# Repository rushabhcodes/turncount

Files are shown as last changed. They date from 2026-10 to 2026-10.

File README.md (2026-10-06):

# TurnCount

TurnCount is a 48 mm round, two-layer rotary encoder prototype. The current circuit uses a CR2032 coin cell, a bare Nordic nRF52810-QFAA-R QFN-48, and a low-profile SMD encoder. USB-C charging and the LiPo charger/regulator path have been removed. The coin cell feeds the nRF52810 supply directly; its 1.7–3.6 V operating range accommodates a CR2032 over its discharge curve.

This remains a design review prototype, not a fabrication release. The CR2032 holder, RF layout and antenna tuning need physical review. The nRF52810 requires its supply decoupling, DEC capacitors, ground exposed pad, RF matching network and antenna, which are represented in the circuit.

## Main parts

| Function | Part |
| --- | --- |
| BLE MCU | Nordic nRF52810-QFAA-R, QFN-48; JLCPCB C141828 |
| Battery holder | MY-2032-16 CR2032 holder; JLCPCB C2902340 |
| RF antenna | RFANT3216120A5T; JLCPCB C127629 |
| Encoder | GT-EVA01AA-L1 |

GPIO assignments are P0.11 for A, P0.12 for B, P0.13 for push and P0.14 for the debug LED. SWDIO, SWDCLK and reset are exposed on test pads. The CR2032 holder mounts on the underside; check clearance against any future enclosure before fabrication.

## JLCPCB fabrication settings

The board explicitly uses 0.30 mm drilled through-vias with 0.60 mm copper pads
(0.15 mm radial annular ring), tented on both sides. JLCPCB lists extra charges
for 0.10/0.15 mm via holes and for 0.20/0.25 mm holes with pads below 0.45 mm;
these standard 0.30/0.60 mm vias avoid that small-hole category. Routing uses
0.15 mm minimum trace width and trace-to-pad clearance, 0.15 mm pad clearance,
0.20 mm hole and via-to-pad clearance, 0.45 mm via drill-to-drill clearance,
and 0.30 mm copper
clearance from the routed outline. The encoder's two 0.60 mm non-plated locating
holes exceed the 0.50 mm NPTH minimum.

For the economical PCB quote, use two-layer FR-4, 1.6 mm thickness, 1 oz copper,
green solder mask, standard outline tolerance and tented vias. Do not request
filled/capped vias, blind/buried vias, edge plating or controlled impedance.
Surface finish and assembly services affect the quote separately; confirm the
final Gerbers in JLCPCB's DFM/quote before ordering. Re-export fabrication files
after changing these rules; an older Gerber ZIP does not inherit source changes.

Requirements: <https://jlcpcb.com/capabilities/pcb-capabilities>.

Validation is reproducible with `npm run check`: all eight CLI check types,
TypeScript, the routed build, and the manufacturing dimension audit must pass.
The pin specification check retains two nonblocking warnings for passive imported
encoder/crystal parts without power-pin metadata. Bare test pads have no courtyard.

Verified routes are stored in `routing/pcb-trace-paths.json` and loaded by an
explicit routing phase. Changes to pad locations or footprints require updating
these routes and repeating the checks before exporting. The latest fabrication
bundle and validation summary are saved in `manufacturing/`.

The CLI doctor reports an npm authentication-header logging diagnostic despite
matching registry credentials. This is separate from the circuit checks; registry
publication verifies the active session directly.

## Umbrella enclosure

The default assembly now includes a 60 mm full-depth rotating cover, a snap-in lid,
a base with integrated PCB supports, and a pocket for an accessory-side MagSafe
magnet ring. See [the print and assembly guide](enclosure/ASSEMBLY.md). The complete
PCB remains in `TurnCountBoard.tsx`; `assembly.cadassembly` groups the enclosure
parts alongside it in the default `assembly.device`, following the
[tscircuit assembly documentation](https://docs.tscircuit.com/elements/assembly-cadassembly).

Open `enclosure/output/preview.html` for assembled, exploded, and underside views.
The output directory also includes three printable STL parts, tip-fit coupons,
and assembled/exploded GLB models. Measure the purchased magnet module and fit-test
the small encoder drive before printing the complete enclosure.

## Local decoupling

Each nRF52810 VDD pin now has its own 100 nF capacitor: C1/VDD1,
C2/VDD2, and C15/VDD3. C8–C11 decouple DEC1–DEC4 with the Nordic
reference values. The local supply paths have a 3 mm limit and
`npm run check` verifies their actual continuous top-layer copper paths,
capacitor values, and ground connections. It fails if any local path is
missing or too long. Reference values follow the [Nordic nRF52810
reference circuitry](https://docs.nordicsemi.com/r/bundle/ps_nrf52810/page/ref_circuitry.html). Shared ground routing is checked separately for
connectivity and copper shorts.

The project pins the latest registry releases checked on 6 October 2026:
`tscircuit` 0.0.2745 and `@tscircuit/cli` 0.1.2252. `circuit-json` stays at
0.0.515, the version required by the CLI's peer dependency.

## Build

```sh
npm install
npm run check
```

The PCB uses exact imported JLCPCB footprints for the nRF52810, battery holder, RF antenna, encoder and LED. Check current stock, verify the selected footprints and RF network against the Nordic reference design, and tune the antenna on the assembled board before treating this as a production design.

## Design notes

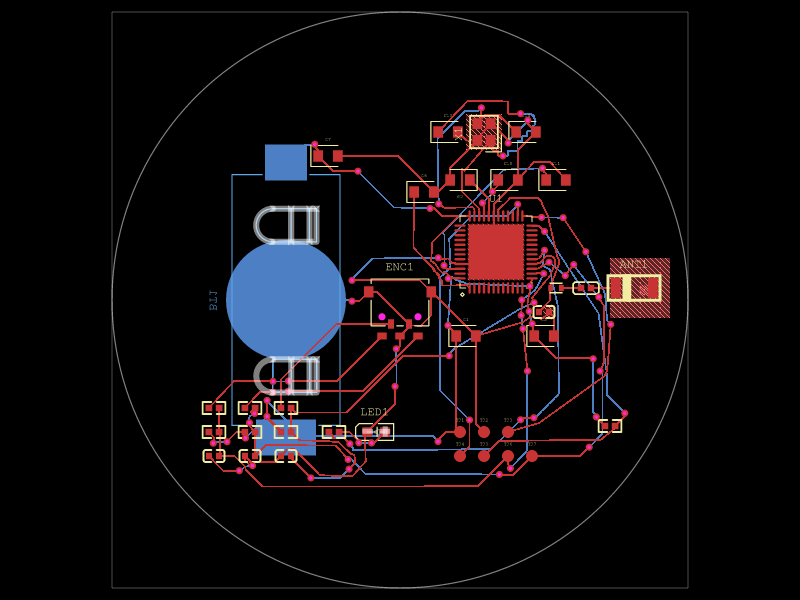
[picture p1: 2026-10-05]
docs/pcb-coin-cell.png

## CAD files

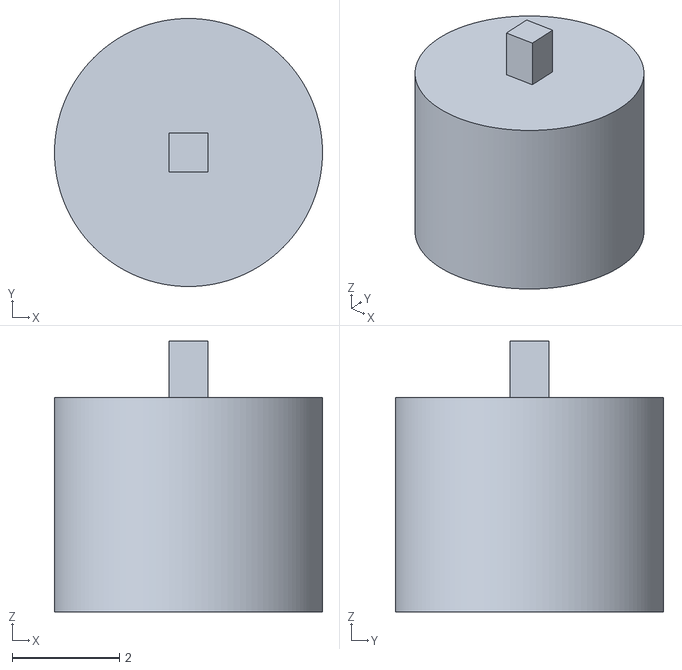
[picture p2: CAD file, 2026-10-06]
enclosure/output/tip-fit-0.72mm.stl
5.00 x 5.00 x 5.05

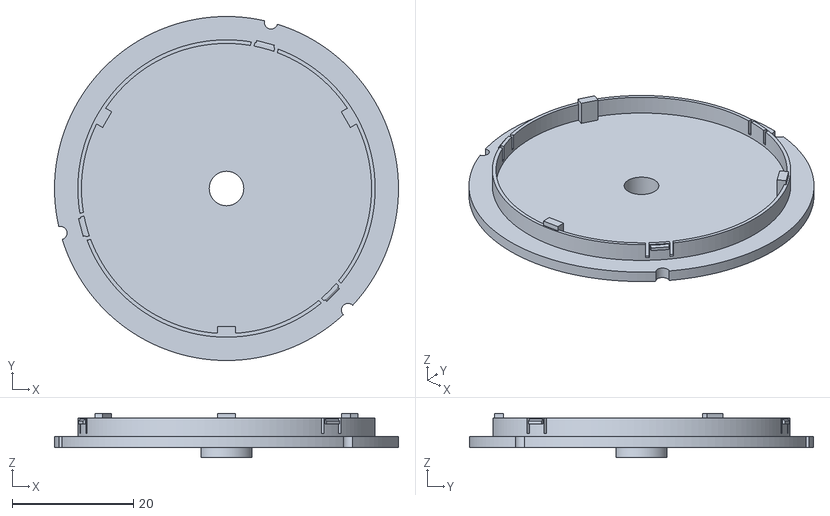
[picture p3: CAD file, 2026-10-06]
enclosure/output/lid.stl
56.8 x 56.8 x 7.30

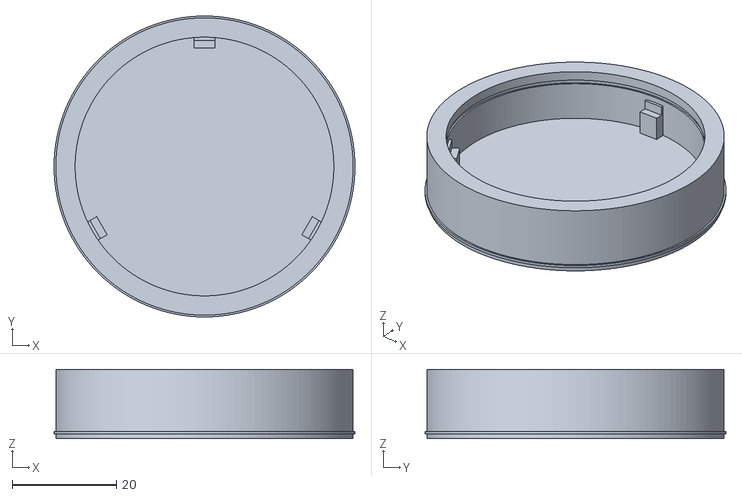
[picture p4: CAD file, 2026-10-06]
enclosure/output/base.stl
57.7 x 57.7 x 13.3

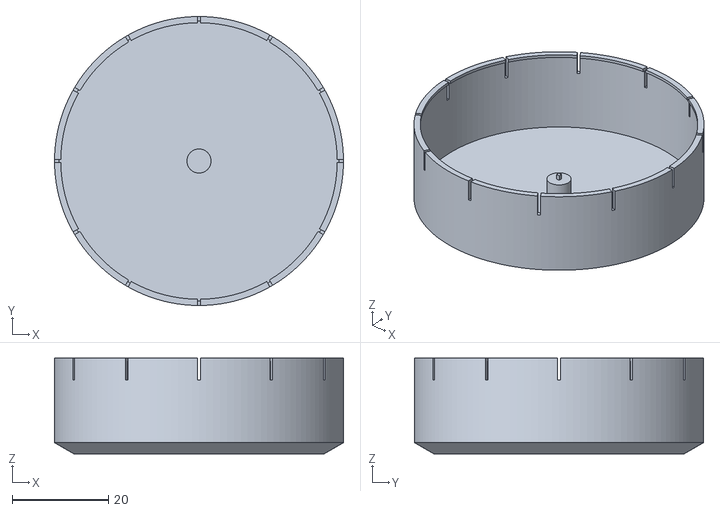
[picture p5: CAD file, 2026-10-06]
enclosure/output/knob.stl
60.0 x 60.0 x 19.9

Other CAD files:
enclosure/output/tip-fit-0.84mm.stl
enclosure/output/tip-fit-0.80mm.stl
enclosure/output/tip-fit-0.76mm.stl

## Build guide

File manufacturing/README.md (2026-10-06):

# TurnCount fabrication bundle — 1.0.19

`turncount-gerbers.zip` contains the latest routed two-layer board export.
Use 1.6 mm FR-4, 1 oz copper, green solder mask, standard outline tolerance,
and tented through-vias for the standard PCB quote.

All 47 plated holes are 0.30 mm with 0.60 mm copper pads. Both mask layers
cover the vias. The two encoder locating holes are 0.60 mm non-plated holes.
`validation-summary.json` records the passing circuit and dimension checks.
Reproduce validation with `npm run check`.

The export also contains BOM and placement data. Battery-holder rotation has
not been automatically verified because the imported footprint lacks a pin-1
location. Check that rotation before ordering assembly. Passive encoder/crystal
power-pin metadata and bare test-pad courtyard warnings remain nonblocking.
The design still requires physical holder review and RF/antenna tuning.

The CLI doctor authentication-header logging diagnostic remains; it does not
change the passing circuit checks. Confirm the final manufacturing quote with
JLCPCB, since finish, assembly, and order options affect pricing separately.

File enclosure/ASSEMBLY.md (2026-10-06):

# TurnCount full-depth dial enclosure

Three printed parts: **base**, **lid**, and **knob**. The 60 mm rotating knob covers the entire PCB and extends down around the 57 mm fixed base, almost to its bottom. Overall height including the phone contact film is 20.7 mm. PCB supports, the encoder drive, and retention snaps are integrated; there are no assembly screws or separate shaft inserts.

## Files and printing

- `output/base.stl`: base with PCB ledges, magnet pocket, and knob retention bead.
- `output/lid.stl`: snap-in lid with PCB clamp fingers and central shaft guide.
- `output/knob.stl`: full-depth rotating cover with integrated square encoder tip.
- `output/tip-fit-*.stl`: optional small test coupons, not assembly parts.
- `output/preview.html`: offline interactive assembly, exploded, and underside views.
- `output/turncount-assembled.glb` and `turncount-exploded.glb`: native tscircuit assembly models.

STLs use millimetres and are positioned on the print bed. Print the base upright. The lid is exported guide side down; support its flat face around the guide. The knob is exported top down, with its skirt and integrated shaft pointing upward. Use a tough material suitable for flexible snaps. A calibrated tough-resin printer is preferable for the small encoder tip; fine-nozzle PETG is a possible prototype route. Test the coupons before committing to the full knob.

The GT-EVA01AA-L1 drawing specifies a 0.8 ± 0.03 mm square drive opening. The nominal printed tip is 0.76 mm. Print coupons from 0.72 to 0.84 mm, choose a gentle sliding fit, and update `squareDrive` in `enclosure/dimensions.ts` if necessary. The actual encoder engagement depth must also be confirmed physically. Never force a tip into the encoder.

## Purchased items

Use an **accessory-side MagSafe magnet module**, correctly polarized, preferably supplied with its shielding. A plain steel adhesive ring is not the specified magnetic module. The nominal magnetic ring is 54.1 mm outside diameter and 46 mm inside diameter. This pocket is 54.5 mm outside diameter, 45.6 mm inside diameter, and 2.15 mm deep; the complete module including adhesive and shield must fit within the 2 mm modeled envelope. Measure the purchased module before printing.

Add a 0.8 mm soft phone-facing film, approximately 56.8 mm diameter, and three 0.2 mm compliant PCB clamp pads. The ring and film use thin adhesive; the printed assembly itself snaps together. The underside reference geometry represents the module envelope, not its individual magnet segments.

## Assembly

1. Secure the correctly oriented magnet module in the underside pocket. Apply the soft contact film so no hard print edge contacts the phone.
2. Install the battery, then seat the PCB on the three built-in base ledges. The supports keep the bottom battery holder clear of the floor.
3. Apply the three thin clamp pads beneath the lid fingers. Align the lid clips with the base groove and press the lid into place evenly.
4. Gently align the knob's integrated square tip with the encoder opening through the lid guide. Lower the knob and flex its lower skirt over the base retention bead. Do not use the snap force to force the shaft into the encoder.
5. Confirm a full turn, free return after pressing, and secure retention. The cover has 0.2 mm of modeled press travel. Its rim remains approximately 0.65 mm above the phone contact surface at full press.

For servicing, remove the device from the phone, ease the flexible lower skirt outward and lift the knob evenly. The lid has three edge notches for gentle release.

## Geometry and validation

The knob's 12 short skirt slots provide flex for assembly. The lower lip catches the base bead when lifted; the operating position leaves room to rotate and press. The lid bore guides the shaft while the base supports carry PCB loads.

`npm run enclosure:export` exports watertight meshes with the Manifold kernel and checks material intersections at eleven knob angles, both released and pressed. It also checks the PCB, battery-holder envelope, magnet pocket, and conservative top-side component envelopes. These checks cover operating clearances, not material flex, wear, magnetic holding force, or real print tolerances. Fit-test the shaft and snaps and check antenna performance with the magnet and enclosure installed before production.

The assembly uses documented `assembly.device` and `assembly.printedpart` elements, with the unchanged PCB in `TurnCountBoard.tsx`.

References: [tscircuit assembly](https://docs.tscircuit.com/elements/assembly-device), [printed parts](https://docs.tscircuit.com/elements/assembly-printedpart), [encoder drawing](https://datasheet.lcsc.com/datasheet/pdf/d558dce12d76d23321eaeb216a98bcc8.pdf), and [Apple accessory guidelines](https://developer.apple.com/accessories/Accessory-Design-Guidelines.pdf).

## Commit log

2026-10-02 Add TurnCount circuit draft and snapshots
2026-10-02 Use no-download tscircuit imports for encoder and holder
    [MDBT42Q.step]
2026-10-02 Use JLCPCB SMD encoder on a circular 48 mm prototype
2026-10-02 Add USB-C rechargeable supply and low-profile JLCPCB encoder
2026-10-03 Add rechargeable TurnCount enclosure and updated PCB
    [01_lower_tray.stl, 01_lower_tray_assembly.stl, 02_upper_cover.stl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]
2026-10-03 Clarify schematic annotations and labels
2026-10-03 Sync schematic release version
2026-10-03 Use GLB enclosure models and 3MF print files
    [01_lower_tray.3mf, 01_lower_tray.stl, 01_lower_tray_assembly.stl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]
2026-10-03 Use OBJ enclosure models for website 3D viewer
    [01_lower_tray_assembly.obj, 02_upper_cover_assembly.obj, 03_rotating_cap_assembly.obj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]
2026-10-03 Fix coin-cell PCB routing checks
2026-10-03 Simplify coin-cell enclosure
    [01_lower_tray.3mf, 01_lower_tray_assembly.obj, 02_upper_cover.3mf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]
2026-10-03 Remove enclosure and clean schematic warnings
    [01_lower_tray.3mf, 01_lower_tray_assembly.obj, 02_upper_cover.3mf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]
2026-10-04 Center coin cell and refine board layout
2026-10-05 Refresh published previews for verified PCB layout
2026-10-06 Add assembled umbrella enclosure and fix local decoupling
    [base.stl, knob.stl, lid.stl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]
2026-10-06 Sync version with native assembly registry release
